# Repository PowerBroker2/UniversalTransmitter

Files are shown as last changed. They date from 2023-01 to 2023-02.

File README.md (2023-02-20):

# UniversalTransmitter
 <br /><br />

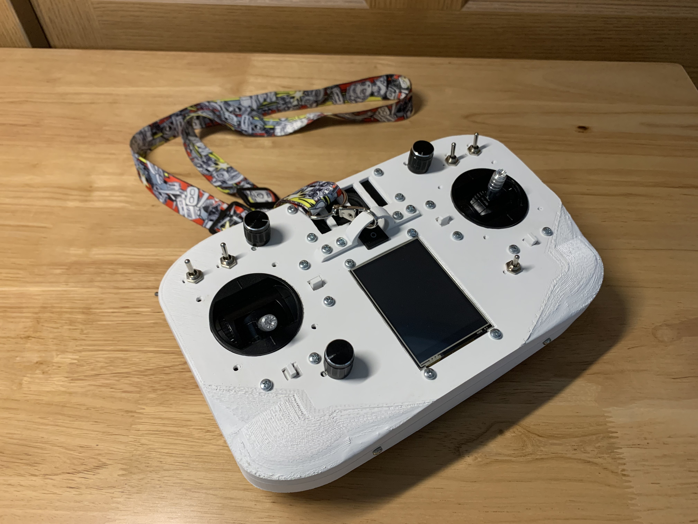
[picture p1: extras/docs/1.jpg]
Your image title


This is an open-source, Arduino-based handheld transmitter (See demo video [here](https://www.youtube.com/watch?v=4R8QFhH_IYU)). This handheld transmitter can be used in any robotics application that requires user input (i.e., RC car, RC airplane, robotic arm, etc.) and includes the following features:

- Teensy 4.1 microcontroller
- [2.8" TFT touchscreen](https://www.amazon.com/gp/product/B09XHJ9KRX/ref=ppx_yo_dt_b_search_asin_title?ie=UTF8&psc=1)
- Lanyard clip
- 1 [3.5mm buddy box signal jack](https://www.amazon.com/gp/product/B07KY8NMD5/ref=ppx_yo_dt_b_search_asin_title?ie=UTF8&psc=1)
  - Only tested with a Flysky FS-i6X
- 2 [RC joystick gimbals](https://www.amazon.com/gp/product/B07YCYNBWF/ref=ppx_yo_dt_b_search_asin_title?ie=UTF8&psc=1)
- 8 [4.3mm Joystick trim buttons](https://www.amazon.com/gp/product/B00R17XUFC/ref=ppx_yo_dt_b_search_asin_title?ie=UTF8&psc=1)
- 2 [general analog knobs](https://www.amazon.com/gp/product/B07B64MWRF/ref=ppx_yo_dt_b_search_asin_title?ie=UTF8&psc=1)
- 5 [toggle switches](https://www.amazon.com/gp/product/B079JBF815/ref=ppx_yo_dt_b_search_asin_title?ie=UTF8&psc=1)
- 1 [tri-state switch](https://www.amazon.com/gp/product/B07QC6T4GW/ref=ppx_yo_dt_b_search_asin_title?ie=UTF8&psc=1)
- 1 [speaker](https://www.amazon.com/gp/product/B0738NLFTG/ref=ppx_yo_dt_b_search_asin_title?ie=UTF8&psc=1)
  - Can be controlled with a [DFPlayerMini](https://www.amazon.com/gp/product/B089D5NLW1/ref=ppx_yo_dt_b_search_asin_title?ie=UTF8&psc=1) or [I2S module](https://www.amazon.com/gp/product/B07PS653CD/ref=ppx_yo_dt_b_search_asin_title?ie=UTF8&psc=1)
  - 1 [volume knob](https://www.amazon.com/gp/product/B07B64MWRF/ref=ppx_yo_dt_b_search_asin_title?ie=UTF8&psc=1)
- 2 power supplies
  - Can use battery pack or external power via [5.5mm barrel jack](https://www.amazon.com/gp/product/B08SJM2G52/ref=ppx_yo_dt_b_search_asin_title?ie=UTF8&psc=1)
  - 1 [power supply select switch](https://www.amazon.com/gp/product/B079JBF815/ref=ppx_yo_dt_b_search_asin_title?ie=UTF8&psc=1)
- 1 [ESP8266 ESP-01S WiFi module](https://www.amazon.com/gp/product/B09J2KPHTN/ref=ppx_yo_dt_b_search_asin_title?ie=UTF8&psc=1)
- 1 [NRF24L01+ 2.4GHz RF module](https://www.amazon.com/gp/product/B00LX47OCY/ref=ppx_yo_dt_b_search_asin_title?ie=UTF8&psc=1)
- 1 [BLE](https://www.amazon.com/gp/product/B01N4P7T0H/ref=ox_sc_saved_title_8?smid=&psc=1) or [classic BT module slot](https://www.amazon.com/gp/product/B07VL725T8/ref=ppx_yo_dt_b_search_asin_title?ie=UTF8&psc=1)
- [RS485](https://www.amazon.com/gp/product/B00NIOLNAG/ref=ppx_yo_dt_b_search_asin_title?ie=UTF8&psc=1) external interface via 2 [RJ45 jacks](https://www.amazon.com/gp/product/B09MBP7ZLR/ref=ppx_yo_dt_b_search_asin_title?ie=UTF8&psc=1)
  - Can use this to communicate with external serial radios (i.e., RFD900+ modules)
- Channel mixing
- Channel expo
- Channel reversing

For software examples, there is a sketch for testing basic functionality of the various features found at `.\examples\example`. Additionally, there is a much more complex sketch with advanced software and configuration features found at `.\examples\complex_example`.

Also, the case is 3D printed (ABS or ASA filament preferred). The 3D parts can be found in the `.\extras\print_files` folder. If you want to easily remix any of the pieces, you can use a copy of the original Blend file found at `.\extras\Universal_Transmitter.blend`.

Lastly, the PCBs can be made using the gerber files found at `.\extras\gerber_files`.


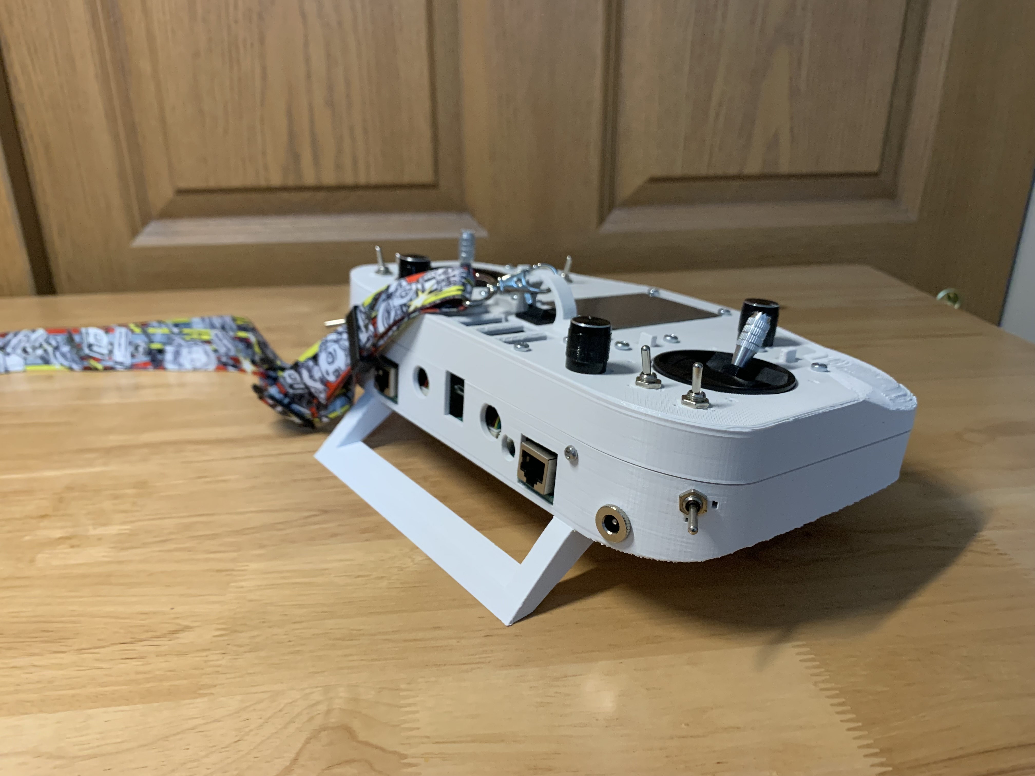
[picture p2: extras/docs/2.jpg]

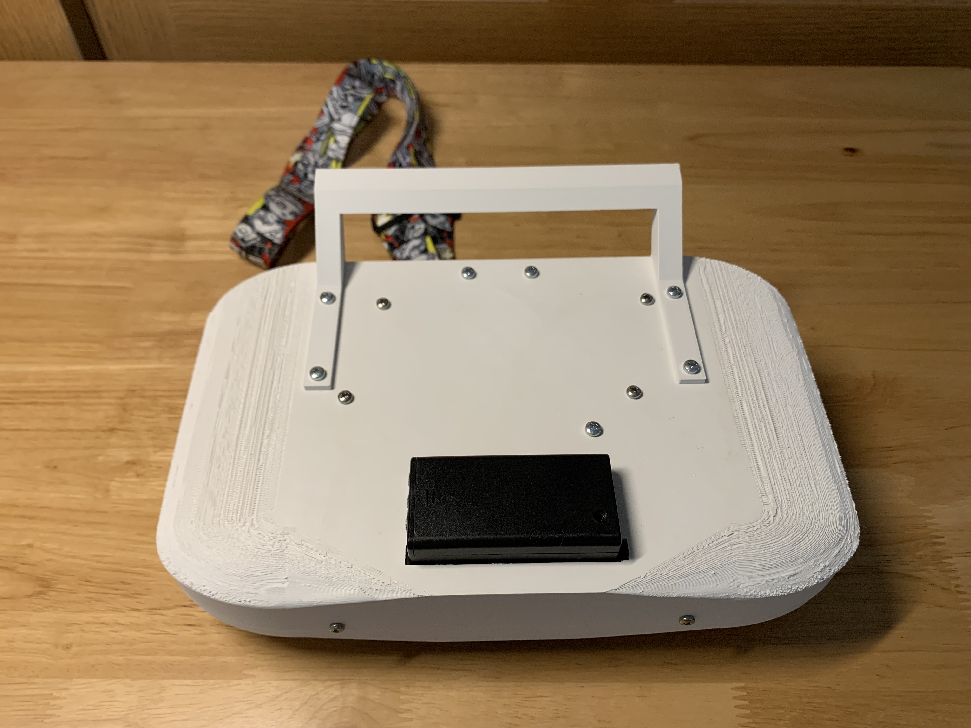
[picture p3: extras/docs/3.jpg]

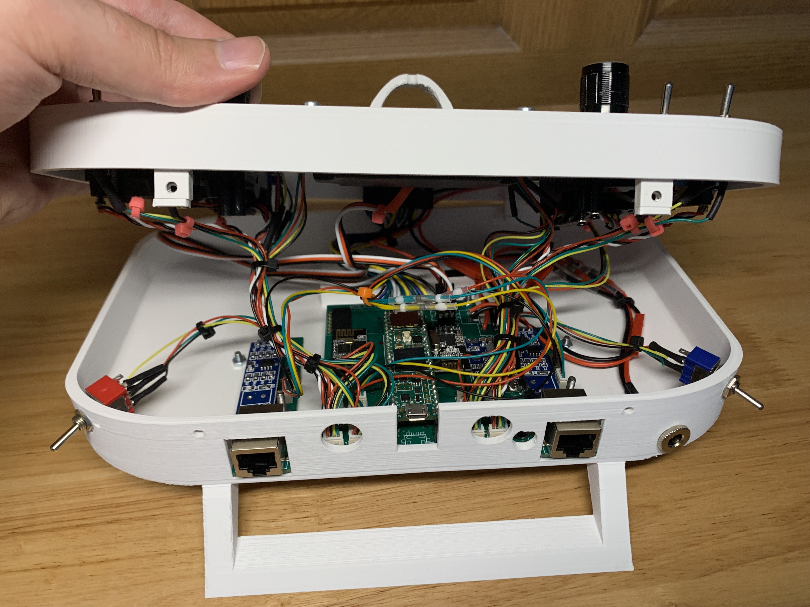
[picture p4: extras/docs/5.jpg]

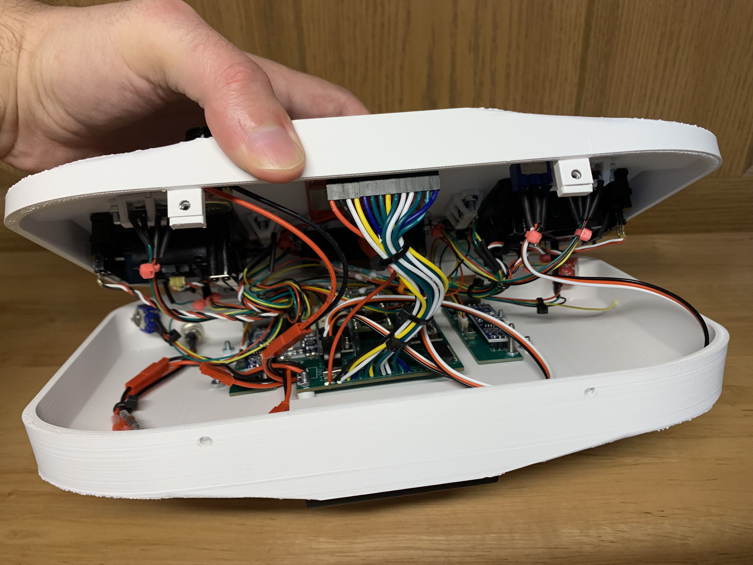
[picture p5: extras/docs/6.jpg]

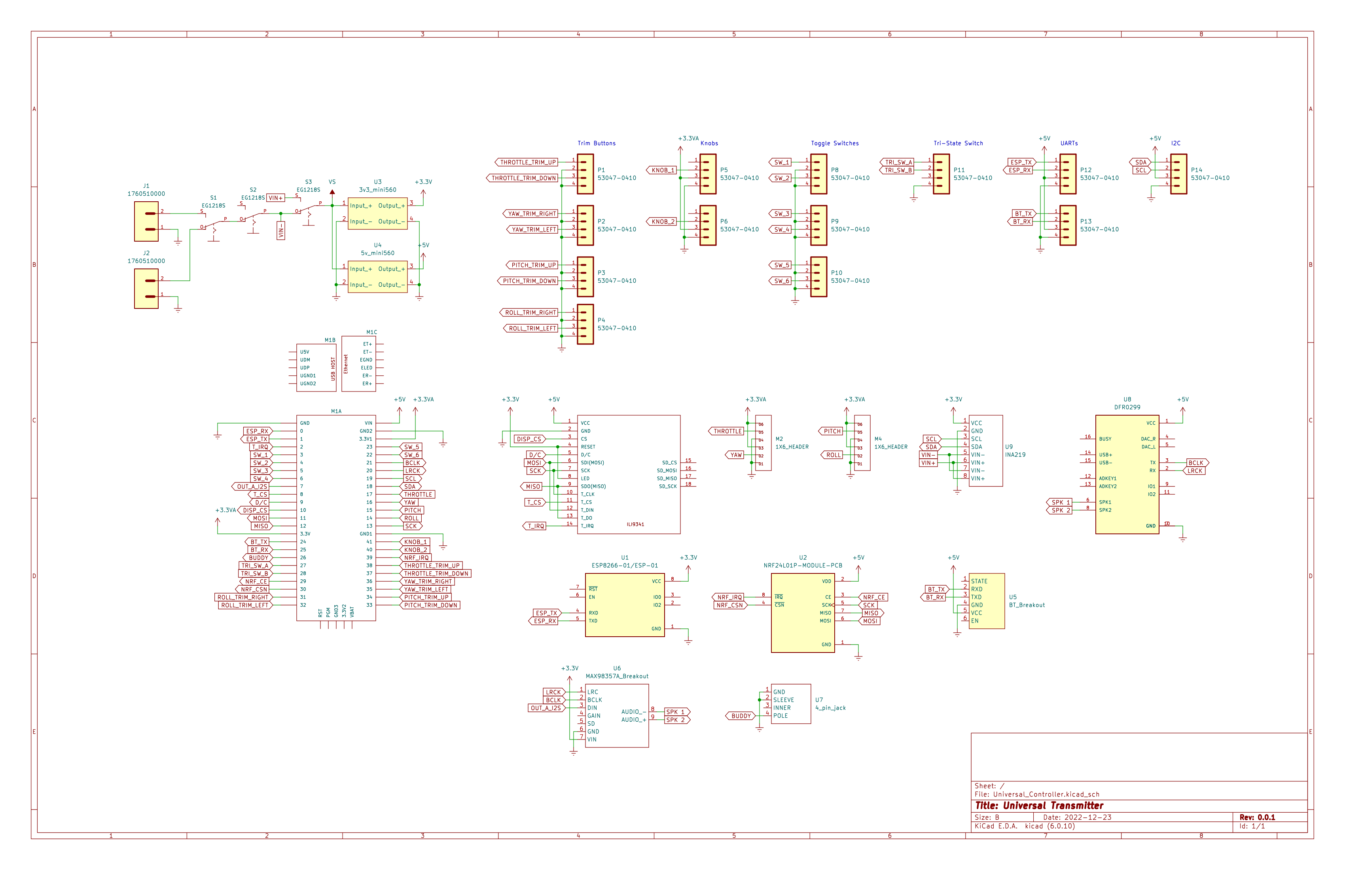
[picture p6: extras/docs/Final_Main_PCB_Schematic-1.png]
Main PCB Schematic

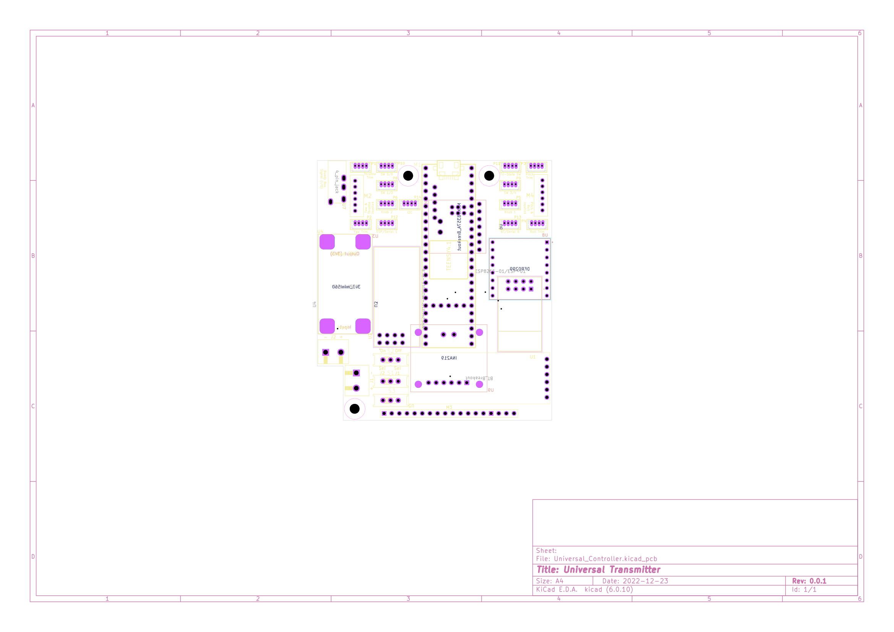
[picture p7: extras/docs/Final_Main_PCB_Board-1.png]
Main PCB Board

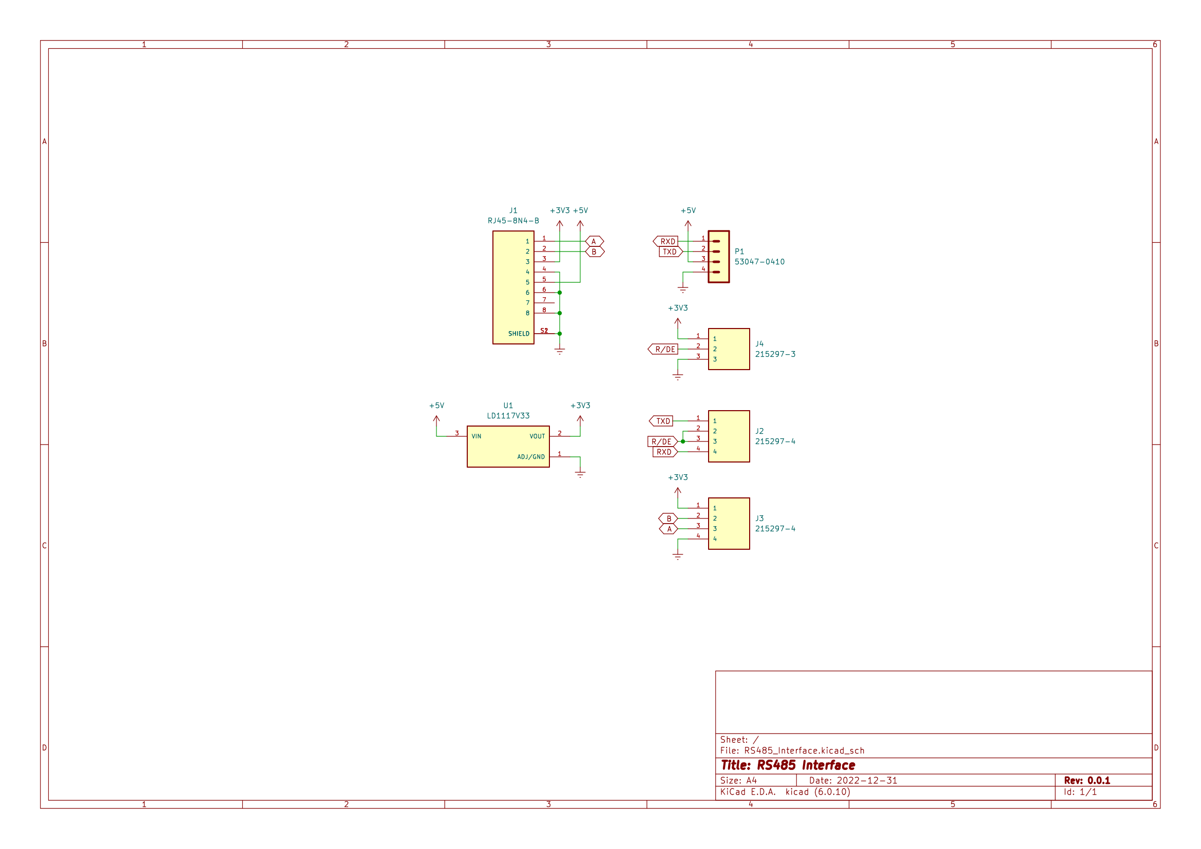
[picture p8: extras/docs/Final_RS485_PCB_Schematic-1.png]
RS485 Interface PCB Schematic

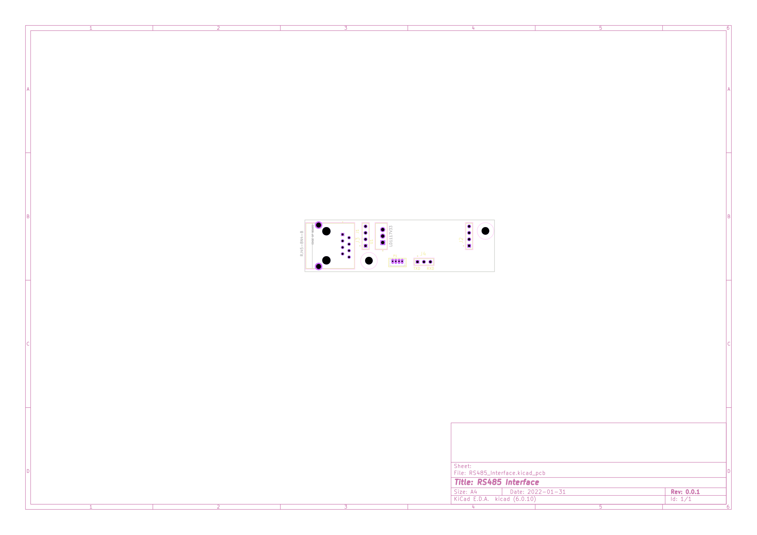
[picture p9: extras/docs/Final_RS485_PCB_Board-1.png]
RS485 Interface PCB Board


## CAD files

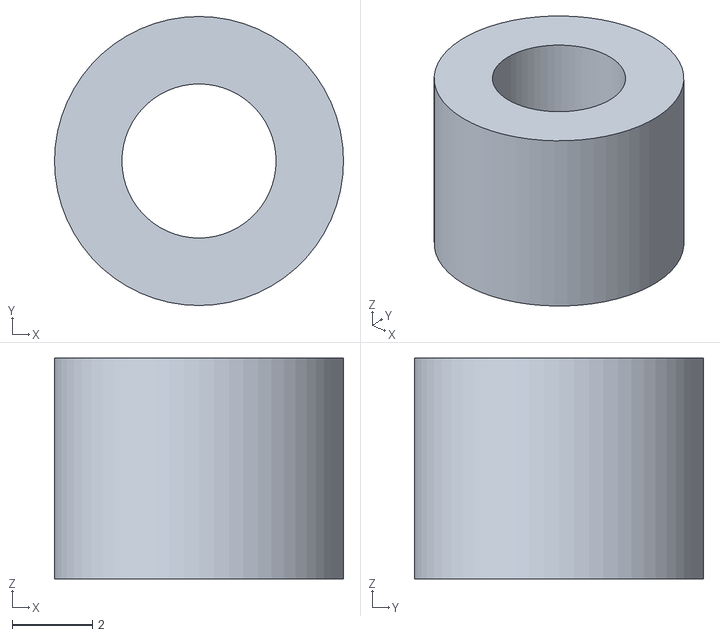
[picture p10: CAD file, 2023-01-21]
extras/print_files/objs/main_standoff.stl
7.20 x 7.20 x 5.50

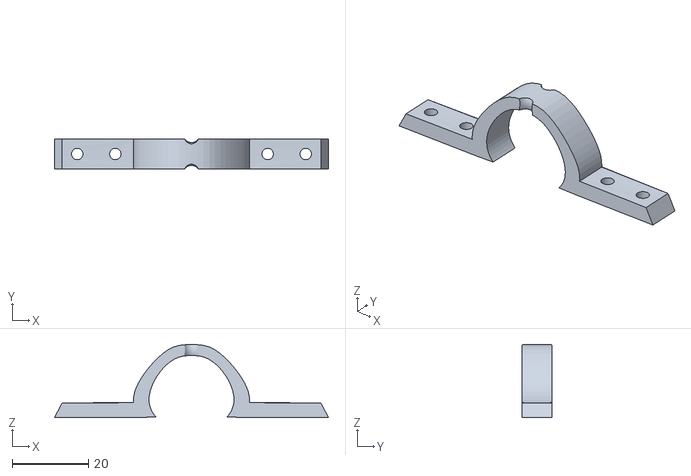
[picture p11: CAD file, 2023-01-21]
extras/print_files/objs/lanyard_clip.stl
71.9 x 8.00 x 19.2

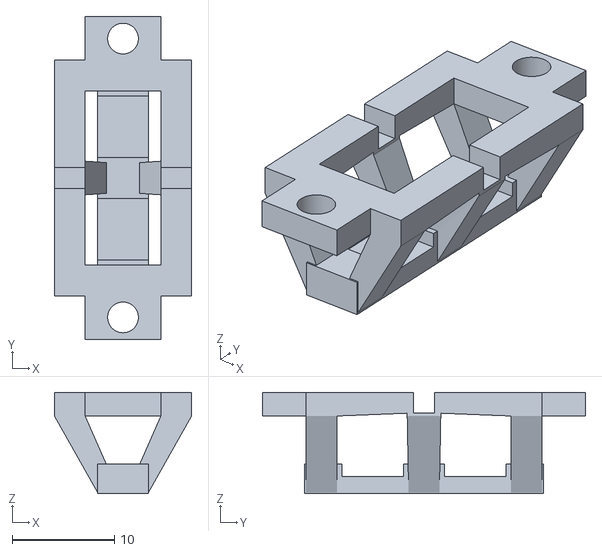
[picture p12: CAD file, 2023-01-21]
extras/print_files/objs/trim_pitch_cradle.stl
13.4 x 31.5 x 9.89

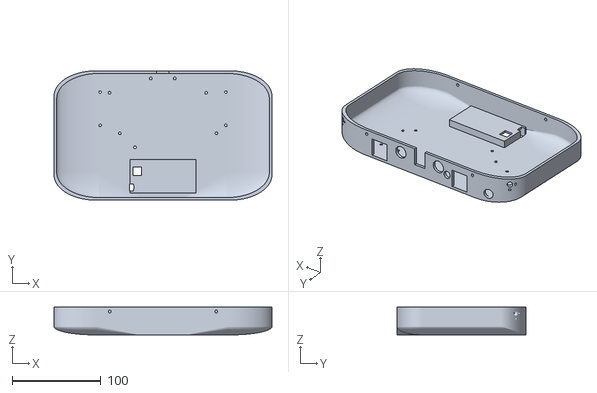
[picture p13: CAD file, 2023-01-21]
extras/print_files/objs/case_bottom.stl
246.0 x 146.0 x 31.5

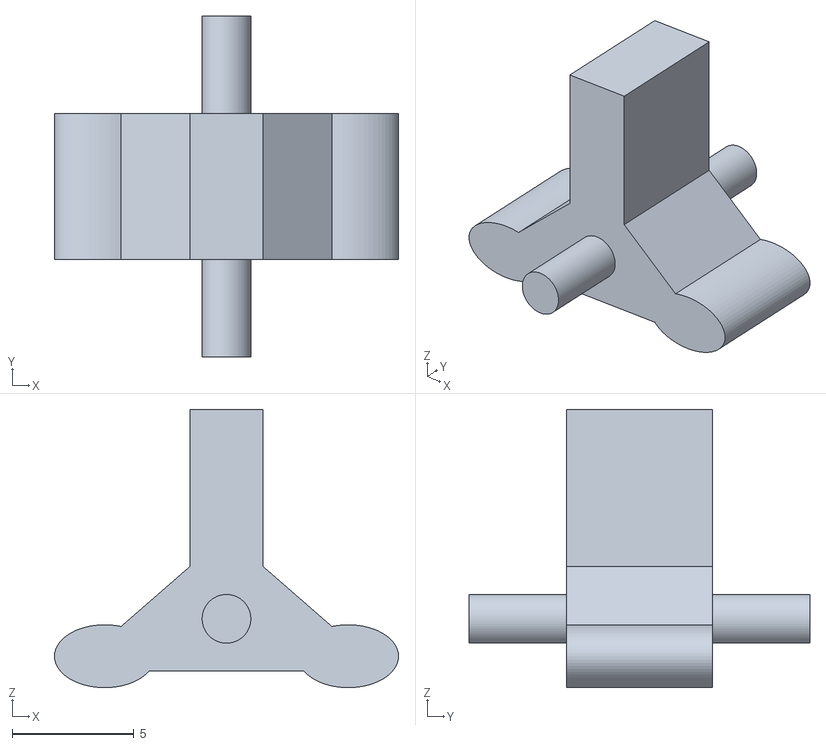
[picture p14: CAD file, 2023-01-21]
extras/print_files/objs/trim_rocker.stl
14.1 x 14.0 x 11.4

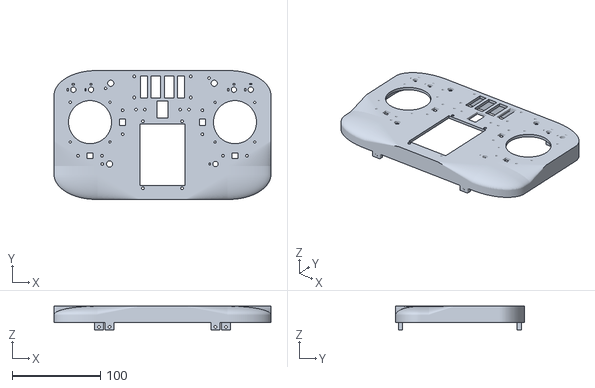
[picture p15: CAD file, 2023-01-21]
extras/print_files/objs/case_top.stl
246.0 x 146.0 x 26.7

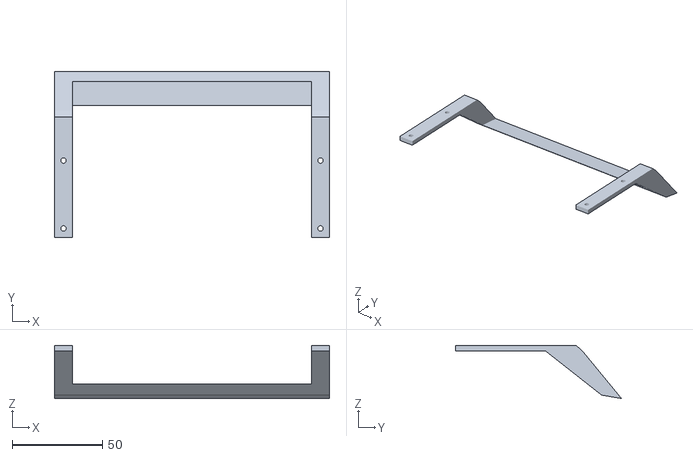
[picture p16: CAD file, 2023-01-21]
extras/print_files/objs/case_stand.stl
152.0 x 91.8 x 29.4

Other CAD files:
extras/print_files/objs/trim_roll_cradle.stl
extras/print_files/objs/trim_yaw_cradle.stl
extras/print_files/objs/trim_throttle_cradle.stl

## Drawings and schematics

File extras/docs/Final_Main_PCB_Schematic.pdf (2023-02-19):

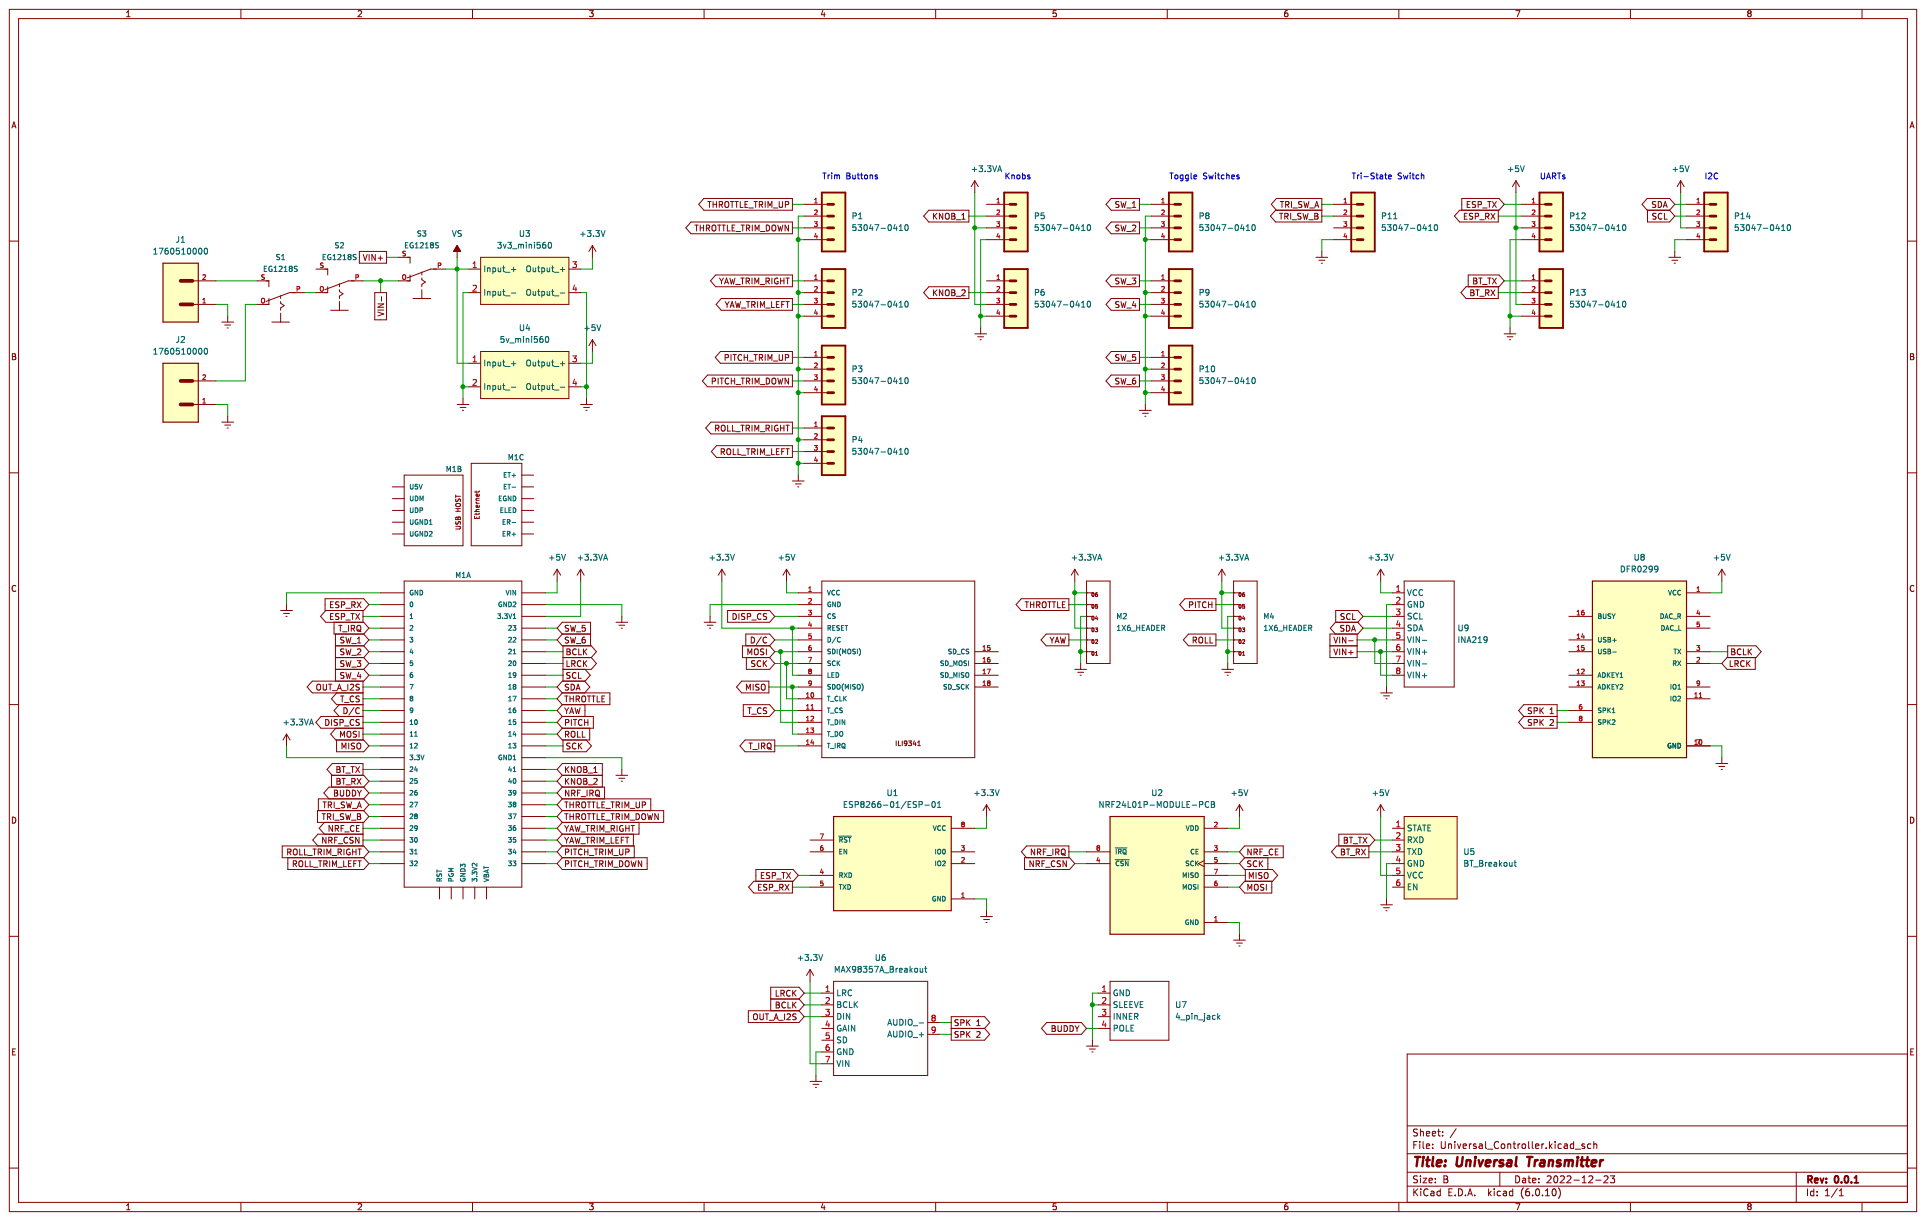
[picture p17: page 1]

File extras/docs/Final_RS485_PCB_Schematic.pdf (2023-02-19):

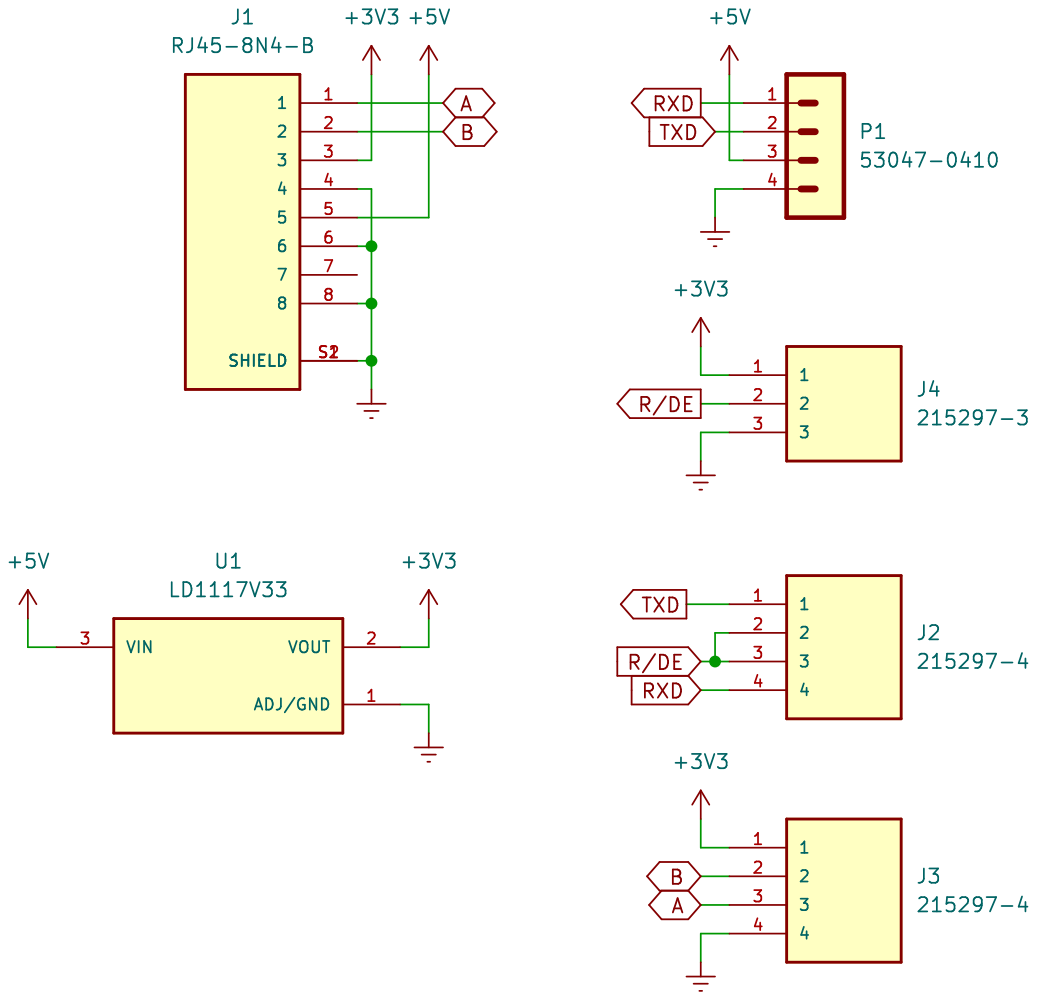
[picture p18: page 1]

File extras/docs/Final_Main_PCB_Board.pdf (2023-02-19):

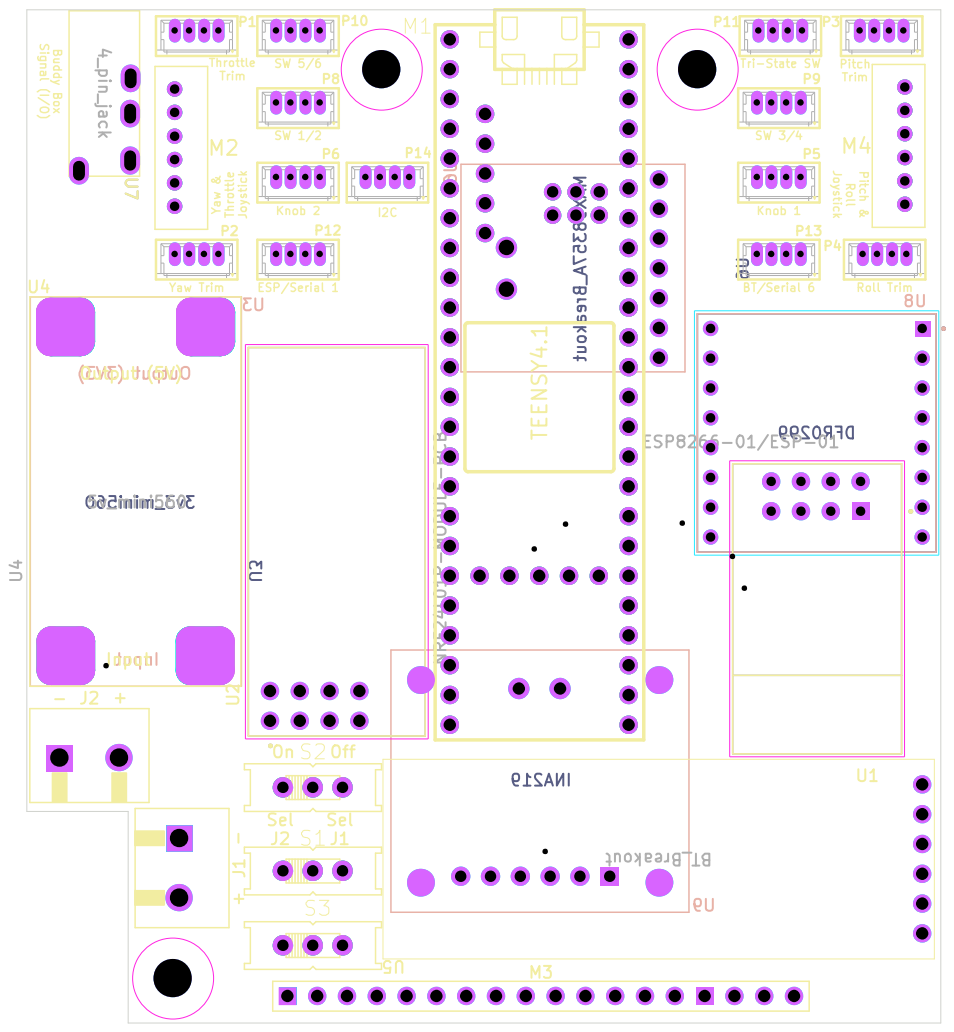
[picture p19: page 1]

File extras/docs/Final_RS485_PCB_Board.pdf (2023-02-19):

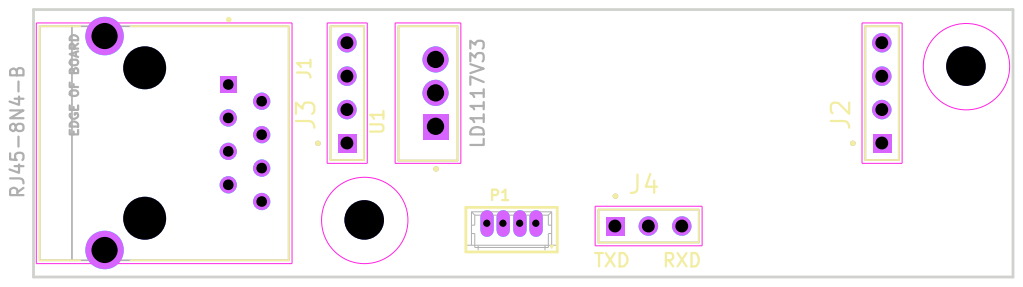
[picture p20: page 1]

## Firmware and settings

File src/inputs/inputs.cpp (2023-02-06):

#include "Arduino.h"
#include "OneButton.h"
#include "TeensyTimerTool.h"
#include "inputs.h"




using namespace TeensyTimerTool;




/*
* ****************** Switches ******************
*/
extern const int SW_1_PIN = 3;
extern const int SW_2_PIN = 4;
extern const int SW_3_PIN = 5;
extern const int SW_4_PIN = 6;
extern const int SW_5_PIN = 23;
extern const int SW_6_PIN = 22;

extern const int TRI_SW_A_PIN = 27;
extern const int TRI_SW_B_PIN = 28;




channel sw_1_ch;
channel sw_2_ch;
channel sw_3_ch;
channel sw_4_ch;
channel sw_5_ch;
channel sw_6_ch;
channel tri_sw_a_ch;
channel tri_sw_b_ch;




int sw_1_state = 0;
int sw_2_state = 0;
int sw_3_state = 0;
int sw_4_state = 0;
int sw_5_state = 0;
int sw_6_state = 0;

int tri_sw_a_state = 0;
int tri_sw_b_state = 0;

volatile bool sw_1_switched;
volatile bool sw_2_switched;
volatile bool sw_3_switched;
volatile bool sw_4_switched;
volatile bool sw_5_switched;
volatile bool sw_6_switched;

volatile bool tri_sw_a_switched;
volatile bool tri_sw_b_switched;




FASTRUN void SW1ISR()
{
	int prevState = sw_1_state;
	sw_1_state = digitalReadFast(SW_1_PIN);

	if (prevState != sw_1_state)
	{
		sw_1_switched = true;
	}
}

FASTRUN void SW2ISR()
{
	int prevState = sw_2_state;
	sw_2_state = digitalReadFast(SW_2_PIN);

	if (prevState != sw_2_state)
	{
		sw_2_switched = true;
	}
}

FASTRUN void SW3ISR()
{
	int prevState = sw_3_state;
	sw_3_state = digitalReadFast(SW_3_PIN);

	if (prevState != sw_3_state)
	{
		sw_3_switched = true;
	}
}

FASTRUN void SW4ISR()
{
	int prevState = sw_4_state;
	sw_4_state = digitalReadFast(SW_4_PIN);

	if (prevState != sw_4_state)
	{
		sw_4_switched = true;
	}
}

FASTRUN void SW5ISR()
{
	int prevState = sw_5_state;
	sw_5_state = digitalReadFast(SW_5_PIN);

	if (prevState != sw_5_state)
	{
		sw_5_switched = true;
	}
}

FASTRUN void SW6ISR()
{
	int prevState = sw_6_state;
	sw_6_state = digitalReadFast(SW_6_PIN);

	if (prevState != sw_6_state)
	{
		sw_6_switched = true;
	}
}


FASTRUN void TRISWAISR()
{
	int prevState = tri_sw_a_state;
	tri_sw_a_state = digitalReadFast(TRI_SW_A_PIN);

	if (prevState != tri_sw_a_state)
	{
		tri_sw_a_switched = true;
	}
}

FASTRUN void TRISWBISR()
{
	int prevState = tri_sw_b_state;
	tri_sw_b_state = digitalReadFast(TRI_SW_B_PIN);

	if (prevState != tri_sw_b_state)
	{
		tri_sw_b_switched = true;
	}
}





void setupSwitches()
{
	pinMode(SW_1_PIN, INPUT_PULLUP);
	pinMode(SW_2_PIN, INPUT_PULLUP);
	pinMode(SW_3_PIN, INPUT_PULLUP);
	pinMode(SW_4_PIN, INPUT_PULLUP);
	pinMode(SW_5_PIN, INPUT_PULLUP);
	pinMode(SW_6_PIN, INPUT_PULLUP);

	pinMode(TRI_SW_A_PIN, INPUT_PULLUP);
	pinMode(TRI_SW_B_PIN, INPUT_PULLUP);

	delay(1); // SW 4 doesn't initialize correctly without this for some reason

	sw_1_state = digitalReadFast(SW_1_PIN);
	sw_2_state = digitalReadFast(SW_2_PIN);
	sw_3_state = digitalReadFast(SW_3_PIN);
	sw_4_state = digitalReadFast(SW_4_PIN);
	sw_5_state = digitalReadFast(SW_5_PIN);
	sw_6_state = digitalReadFast(SW_6_PIN);

	tri_sw_a_state = digitalReadFast(TRI_SW_A_PIN);
	tri_sw_b_state = digitalReadFast(TRI_SW_B_PIN);
	
	attachInterrupt(SW_1_PIN, SW1ISR, CHANGE);
	attachInterrupt(SW_2_PIN, SW2ISR, CHANGE);
	attachInterrupt(SW_3_PIN, SW3ISR, CHANGE);
	attachInterrupt(SW_4_PIN, SW4ISR, CHANGE);
	attachInterrupt(SW_5_PIN, SW5ISR, CHANGE);
	attachInterrupt(SW_6_PIN, SW6ISR, CHANGE);

	attachInterrupt(TRI_SW_A_PIN, TRISWAISR, CHANGE);
	attachInterrupt(TRI_SW_B_PIN, TRISWBISR, CHANGE);

	sw_1_ch.setPinNum(SW_1_PIN);
	sw_1_ch.setChNum(SW_1_CH);
	sw_1_ch.setIsAn(false);

	sw_2_ch.setPinNum(SW_2_PIN);
	sw_2_ch.setChNum(SW_2_CH);
	sw_2_ch.setIsAn(false);

	sw_3_ch.setPinNum(SW_3_PIN);
	sw_3_ch.setChNum(SW_3_CH);
	sw_3_ch.setIsAn(false);

	sw_4_ch.setPinNum(SW_4_PIN);
	sw_4_ch.setChNum(SW_4_CH);
	sw_4_ch.setIsAn(false);

	sw_5_ch.setPinNum(SW_5_PIN);
	sw_5_ch.setChNum(SW_5_CH);
	sw_5_ch.setIsAn(false);

	sw_6_ch.setPinNum(SW_6_PIN);
	sw_6_ch.setChNum(SW_6_CH);
	sw_6_ch.setIsAn(false);

	tri_sw_a_ch.setPinNum(TRI_SW_A_PIN);
	tri_sw_a_ch.setChNum(TRI_A_CH);
	tri_sw_a_ch.setIsAn(false);

	tri_sw_b_ch.setPinNum(TRI_SW_B_PIN);
	tri_sw_b_ch.setChNum(TRI_B_CH);
	tri_sw_b_ch.setIsAn(false);
}




/*
* ****************** Buttons ******************
*/
extern const int PITCH_TRIM_UP_PIN      = 34;
extern const int PITCH_TRIM_DOWN_PIN    = 33;
extern const int ROLL_TRIM_RIGHT_PIN    = 31;
extern const int ROLL_TRIM_LEFT_PIN     = 32;
extern const int YAW_TRIM_RIGHT_PIN     = 36;
extern const int YAW_TRIM_LEFT_PIN      = 35;
extern const int THROTTLE_TRIM_UP_PIN   = 38;
extern const int THROTTLE_TRIM_DOWN_PIN = 37;

extern const int MAX_PITCH_TRIM =  1;
extern const int MIN_PITCH_TRIM = -1;

extern const int MAX_ROLL_TRIM =  1;
extern const int MIN_ROLL_TRIM = -1;

extern const int MAX_YAW_TRIM =  1;
extern const int MIN_YAW_TRIM = -1;

extern const int MAX_THROTTLE_TRIM =  1;
extern const int MIN_THROTTLE_TRIM = -1;

extern const float TRIM_UPDATE_VAL = 0.01;




OneButton pitch_trim_up = OneButton(
	PITCH_TRIM_UP_PIN,    // Input pin for the button
	true,                 // Button is active LOW
	true                  // Enable internal pull-up resistor
);

OneButton pitch_trim_down = OneButton(
	PITCH_TRIM_DOWN_PIN,    // Input pin for the button
	true,                   // Button is active LOW
	true                    // Enable internal pull-up resistor
);

OneButton roll_trim_right = OneButton(
	ROLL_TRIM_RIGHT_PIN,   // Input pin for the button
	true,                  // Button is active LOW
	true                   // Enable internal pull-up resistor
);

OneButton roll_trim_left = OneButton(
	ROLL_TRIM_LEFT_PIN,    // Input pin for the button
	true,                  // Button is active LOW
	true                   // Enable internal pull-up resistor
);

OneButton yaw_trim_right = OneButton(
	YAW_TRIM_RIGHT_PIN,   // Input pin for the button
	true,                 // Button is active LOW
	true                  // Enable internal pull-up resistor
);

OneButton yaw_trim_left = OneButton(
	YAW_TRIM_LEFT_PIN,    // Input pin for the button
	true,                 // Button is active LOW
	true                  // Enable internal pull-up resistor
);

OneButton throttle_trim_up = OneButton(
	THROTTLE_TRIM_UP_PIN,    // Input pin for the button
	true,                    // Button is active LOW
	true                     // Enable internal pull-up resistor
);

OneButton throttle_trim_down = OneButton(
	THROTTLE_TRIM_DOWN_PIN,    // Input pin for the button
	true,                      // Button is active LOW
	true                       // Enable internal pull-up resistor
);




volatile float pitchTrimVal    = 0;
volatile float rollTrimVal     = 0;
volatile float yawTrimVal      = 0;
volatile float throttleTrimVal = 0;

volatile bool pitchTrimValUpdated;
volatile bool rollTrimValUpdated;
volatile bool yawTrimValUpdated;
volatile bool throttleTrimValUpdated;
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

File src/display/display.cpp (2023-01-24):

#include "Arduino.h"
#include "Adafruit_GFX.h"
#include "SPI.h"
#include "Wire.h"
#include "Adafruit_ILI9341.h"
#include "XPT2046_Touchscreen.h"
#include "TeensyTimerTool.h"




using namespace TeensyTimerTool;




extern const float TOUCH_FREQ   = 30; // Hz
extern const float TOUCH_PERIOD = 1.0 / TOUCH_FREQ; // s

extern const int DISP_CS_PIN = 10;
extern const int DC_PIN      = 9;
extern const int T_CS_PIN    = 8;
extern const int T_IRQ_PIN   = 2;

extern volatile const int TOUCH_TIME_THRESH = 0.2 * 1e6; // us




PeriodicTimer       touchTimer;
XPT2046_Touchscreen ts(T_CS_PIN, T_IRQ_PIN);
Adafruit_ILI9341    tft(DISP_CS_PIN, DC_PIN);
TS_Point            ts_point;




volatile long time_touched  = 0;
volatile bool touch_handled = true;




void enableTS()    { digitalWriteFast(DISP_CS_PIN, HIGH);  digitalWriteFast(T_CS_PIN, LOW);  }
void enableTFT()   { digitalWriteFast(DISP_CS_PIN, LOW);   digitalWriteFast(T_CS_PIN, HIGH); }
void disableTS()   { digitalWriteFast(T_CS_PIN,    HIGH);                                    }
void disableTFT()  { digitalWriteFast(DISP_CS_PIN, HIGH);                                    }
void disableDisp() { digitalWriteFast(DISP_CS_PIN, HIGH);  digitalWriteFast(T_CS_PIN, HIGH); }

FASTRUN void __attribute__((weak)) whenTouched()
{
    if (ts.tirqTouched())
    {
        disableTFT();
        enableTS();
      
        if (ts.touched())
        {
            long currTime = micros();

            if ((currTime - time_touched) >= TOUCH_TIME_THRESH)
            {
                ts_point      = ts.getPoint();
                touch_handled = false;
                time_touched  = currTime;
                
                Serial.print("Pressure = ");
                Serial.print(ts_point.z);
                Serial.print(", x = ");
                Serial.print(ts_point.x);
                Serial.print(", y = ");
                Serial.print(ts_point.y);
                Serial.println();
            }
            else
            {
                ts.getPoint();
            }
        }
        
        disableTS();
    }
}




void setupDisplay()
{
    pinMode(DISP_CS_PIN, OUTPUT);
    pinMode(T_CS_PIN, OUTPUT);

    enableTS();
    ts.begin();
    
    enableTFT();
    tft.begin();

    disableDisp();

    touchTimer.begin(whenTouched, TOUCH_PERIOD * 1e6);
}

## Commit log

2023-01-10 Split sublibraries into separate files, add menu sublibrary placeholder and add switch event flag functionality
2023-01-12 Read initial switch states on startup
2023-01-13 Initialize nRF CS pin to output
2023-01-21 Upload Blend and 3D models
    [case_bottom.stl, case_stand.stl, case_top.stl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]
2023-01-24 Improve reliability of trim button presses
2023-01-26 Reduce trim update value and fix compile warnings
    [inputs.cpp]
2023-01-27 Fix trim and joystick outputs
    [inputs.cpp]
2023-01-27 Add expo and functions to calibrate joysticks/knobs
2023-02-06 Add trim button printouts
2023-02-06 Include expo/mix/reversal for switch outputs
2023-02-19 Add pcb images/doc
